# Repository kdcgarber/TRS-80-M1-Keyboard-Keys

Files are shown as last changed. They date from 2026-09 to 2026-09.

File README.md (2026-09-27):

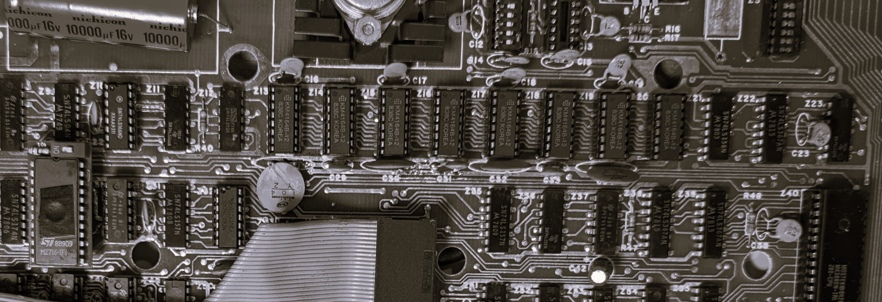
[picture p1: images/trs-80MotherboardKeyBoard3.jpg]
TRS-80-M1-Keyboard-Keys Header


# TRS-80 Model 1 Keyboard Keycaps 
This project is my way of 3D printing my own keycaps for my TRS-80 M1. <br>
I have an M1 motherboard that had no case or keyboard and needed a place to live. <br>
All of the parts needed to do this have been reproduced already by others, but I wanted to play a little more on my own. <br>

This site has .stl and .3mf files I created for my reproduction of my missing 1978 Keycaps.  <br>
For one iteration, I used a modern keyboard with cherry-style keycaps but arranged them with a look to resemble the layout of an original, yet I used an off-the-shelf keyboard.  <br>
Since I was already creating those keys, I thought I'd also create the keys that fit the standard 1978 keys just for fun.  <br>
Even though I didn’t need them currently, it was fun to create and make available for others now to either print their own or take inspiration in their own way to reproduce other keycaps.  <br>

A common element across all the keycaps is the set of glyphs I created to mimic the original Model I keyboard font style.  <br>
I've included those also as .ttf files. In the end, I primarily used Medium .ttf.   <br>
I first tried Regular, but the characters looked too thin.  <br>
I tested Bold as well, but it appeared oversized. So, in true Goldilocks fashion, Medium was just right.  <br>
Because of that, I never went back to refine the Bold version’s glyph shapes. <br>

These keys are inexpensive to reproduce if you have access to a 3D printer.  <br>
The estimated cost of printing a full set in a single-color PLA on my own machine is about $3.37, making them very affordable. <br>

The keys are not really cherry style though they fit the classic + shaped key switches. <br>
I labeled them as cherry because I started with a 60% keyboard that I was replacing that had cherry keycaps.  <br>
The new look is a mix, but maybe more in the DSA keycap style. <br>

There are two styles for the keys with several variations, the Hi-Tek and the Alps. <br>
The Alps I went with a rectangular pattern instead of round stems. <br>
The round stems were a little weaker in design, so I went with the rectangular “+" shape that seemed to work the best. <br>
I don’t have a TRS-80 Alps keyboard to test those on, only the newer "+" shaped keyboards. <br>

<table>
  <tr>
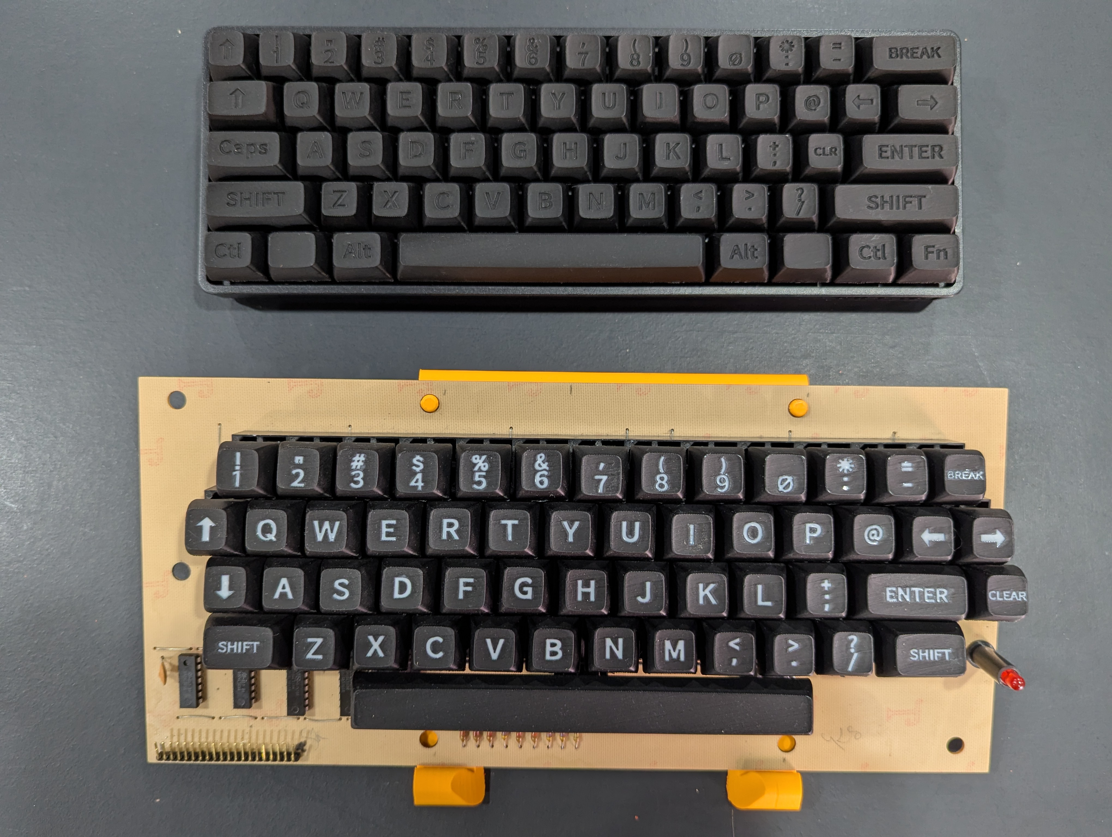
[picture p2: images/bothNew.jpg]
	<td></td>
  </tr>
</table>  

<br>
The keyboard on the top is my Amazon ordered $15 USB keyboard with the new 3d printed keys, next to my first M1 with my replacement 3d PLA keycaps filled then with white UV resin.
Both came out very well, though not profesional purchased keys.
 
## Content in repository
	📂 M1-Fonts		    -- M1 keyboard fonts to be used with key cap creation
	│
	├── TRS80M1-Bold.sfd        - Bold     fontforge editable file
	├── TRS80M1-Bold.ttf        - Bold     Font file
	├── TRS80M1-Medium.sfd      - Medium   fontforge editable file
	├── TRS80M1-Medium.ttf      - Medium   Font file
	├── TRS80M1-Regular.sfd     - Regular  fontforge editable file
	├── TRS80M1-Regular.ttf     - Regular  font file
	│
 	📂 openscad/KeyV2-All
	│
	├─📂 TRS-80-1978-M1/				        -- 1978 style M1 Keys with (HI-Tek) square stems
	│    ├── trs-80-1978-KeyCaps-FromSTL.3mf	-- My edited version I use to print. it's all ready to print more keys
	│    ├── trs-80-1978-KeyCaps.stl		    -- An outputted .stl file with fonts just inset in one color
	│    ├── trs-80-1978-KeyCaps.3mf		    -- An outputted .3mf file with 2 colors if you want to print in 2 colors
	│    └── trs-80-1978-KeyCaps.scad		    -- Run this OpenSCAD file to edit or generate the current keys
	│
	├─📂 TRS-80-1978-M1-KEYPAD/			            -- M1 Key Pad Keys with (Hi-Tek) square stems
	│    ├── trs-80-1978-KeyCaps-KeyPad-FromSTL.3mf	-- My edited version I use to print. it's all ready to print more keys
	│    ├── trs-80-1978-KeyCaps-KeyPad.stl		    -- An outputted .stl file with fonts just inset in one color
	│    ├── trs-80-1978-KeyCaps-KeyPad.3mf		    -- An outputted .3mf file with 2 colors if you want to print in 2 colors
	│    └── trs-80-1978-KeyCaps-KeyPad.scad	    -- Run this OpenSCAD file to edit or generate the current keys
	│
	├─📂 TRS-80-1978-M1-StandardLayoutCherryKeys    				-- Similar the new (ALPS) Cherry key style switches, but only the keys for a new replacment M1 keyboard with the standard + stem connector 
	│    ├── TRS-80-1978-M1-StandardLayoutCherryKeys-FromSTL.3mf	-- My edited version I use to print. it's all ready to print more keys
	│    ├── TRS-80-1978-M1-StandardLayoutCherryKeys.stl			-- An outputted .stl file with fonts just inset in one color
	│    ├── TRS-80-1978-M1-StandardLayoutCherryKeys.3mf			-- An outputted .3mf file with 2 colors if you want to print in 2 colors
	│    └── TRS-80-1978-M1-StandardLayoutCherryKeys.scad			-- Run this OpenSCAD file to edit or generate the current keys
	│
	├─📂 TRS-80-1978-M1-StandardLayoutCherryKeysFlat/			        -- M1 low profile (ALPS) keys with the standard + stem connector 
	│    ├── TRS-80-1978-M1-StandardLayoutCherryKeysFlat-FromSTL.3mf	-- My edited version I use to print. it's all ready to print more keys
	│    ├── TRS-80-1978-M1-StandardLayoutCherryKeysFlat.stl		    -- An outputted .stl file with fonts just inset in one color
	│    ├── TRS-80-1978-M1-StandardLayoutCherryKeysFlat.3mf		    -- An outputted .3mf file with 2 colors if you want to print in 2 colors
	│    └── TRS-80-1978-M1-StandardLayoutCherryKeysFlat.scad	    	-- Run this OpenSCAD file to edit or generate the current keys
	│
	├─📂 TRS-80-1978-M1-StandardLayoutCherryKeysRotatedStems    				-- Similar to the new (ALPS) Cherry key style switches but the stems are rotated for the standard + stem connector 
	│    ├── TRS-80-1978-M1-StandardLayoutCherryKeysRotatedStems-FromSTL.3mf	-- My edited version I use to print. it's all ready to print more keys
	│    ├── TRS-80-1978-M1-StandardLayoutCherryKeysRotatedStems.stl			-- An outputted .stl file with fonts just inset in one color
	│    ├── TRS-80-1978-M1-StandardLayoutCherryKeysRotatedStems.3mf			-- An outputted .3mf file with 2 colors if you want to print in 2 colors
	│    └── TRS-80-1978-M1-StandardLayoutCherryKeysRotatedStems.scad			-- Run this OpenSCAD file to edit or generate the current keys
	│    
	└─📂 TRS-80-M1-60%-Cherry					                -- M1 Keys for a new (ALPS) Cherry key style key switches with the standard + stem connector 
	     ├── trs-80-60% Cherry Key Caps-From-STL.3mf			-- My edited version I use to print. it's all ready to print more keys
	     ├── trs-80-60% Cherry Key Caps.stl				        -- An outputted .stl file with fonts just inset in one color
	     ├── trs-80-60% Cherry Key Caps.3mf				        -- An outputted .3mf file with 2 colors if you want to print in 2 colors
		 └── trs-80-60% Cherry Key Caps.scad			        -- Run this OpenSCAD file to edit or generate the current keys

<br>

## The Keycaps:
I chose to use OpenSCAD to recreate the keycaps for my model 1 keyboards. https://openscad.org/ <br>
I also found a keycap library to get me started which was very helpful.  That template was found at https://github.com/rsheldiii/Keyv2. <br>

I have a Bambu Lab X1 carbon which has a bed size of 256x256x256mm that prints them all very well. <br>
I tried many renditions of the keycaps having the fonts raised and inset and many iterations of placement of the stems of the original keycaps. <br>
I used the regular font shape and only had that single TRS80M1-Medium.ttf installed to ensure I ran with the correct font on the keycaps. <br>

I also recreated characters to represent those on the original keycaps. <br>
I used https://fontforge.org/en-US/downloads/ to help lay those out. <br>
Though none of this is perfect, it creates very nice replacement for M1 keycaps that can be easily 3d printed at home. <br>

The .3mf files that were direct exports of the OpenSCAD creations will print a 2-color keycap if you would prefer. <br>
They do print, but I had poor luck printing any of them in two colors without changing to the Bold font. <br>
I didn’t prefer the look though of the Bold font and chose the two-step approach of adding resin after the single-color print with the medium characters. <br>
My printer does the material handler, so it changes colors for me automatically, though it's purges around 100 times before completing and takes quite a while to print. <br>

In the end I chose the .3mf files with the -FromSTL.3mf ending. <br>
These keycaps are print in a single color with the characters inset in the keycap tops. <br>
I then use a white UV 3d resin to fill the relief and replicate the black keys with white letters. <br>
The resin was added using a craft syringe filled with UV resin and slowly added to each key (also a fiddly task). <br>  
I then set the key under the UV light right away to keep the resin from bleeding into the layer lines. <br>
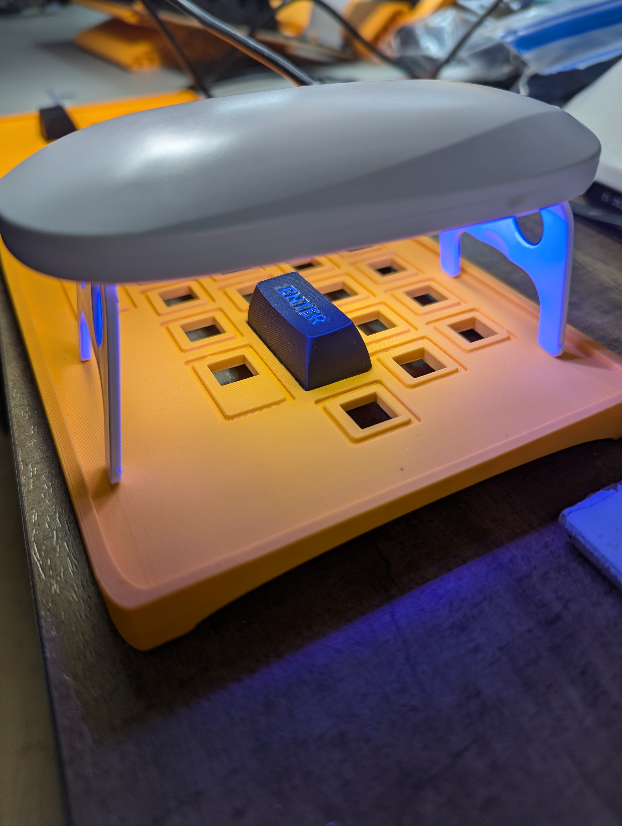
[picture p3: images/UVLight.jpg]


# Samples:

<table>
  <tr>
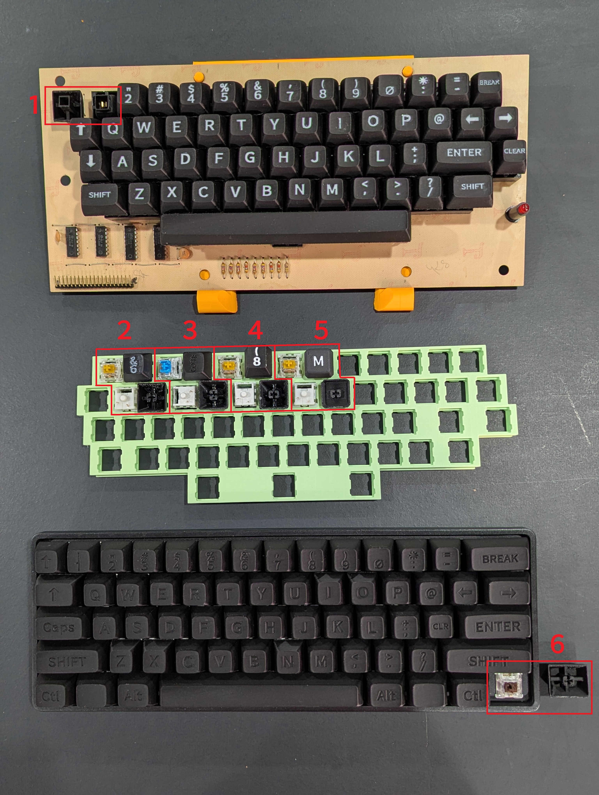
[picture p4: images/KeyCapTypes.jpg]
	<td></td>
  </tr>
</table>

<pre>
1 Original 1978 M1 with square (Hi-Tek) keycap stems
2 Cherry key horizontal and keycap with relief glyphs filled with white resin
3 Keycaps with vertical  layout (this keycap has not been filled with white resin yet)
4 Horizontal black PLA keycaps from .mf3 printed including white PLA glyphs 
5 Horizontal key with low profile black PLA keycaps with white PLA glyphs
6 Standard USB keyboard replaced with black PLA keycaps designed like the 1978 M1 layout
</pre>

### 1978 M1
 -- Number 1 
<table>
  <tr>
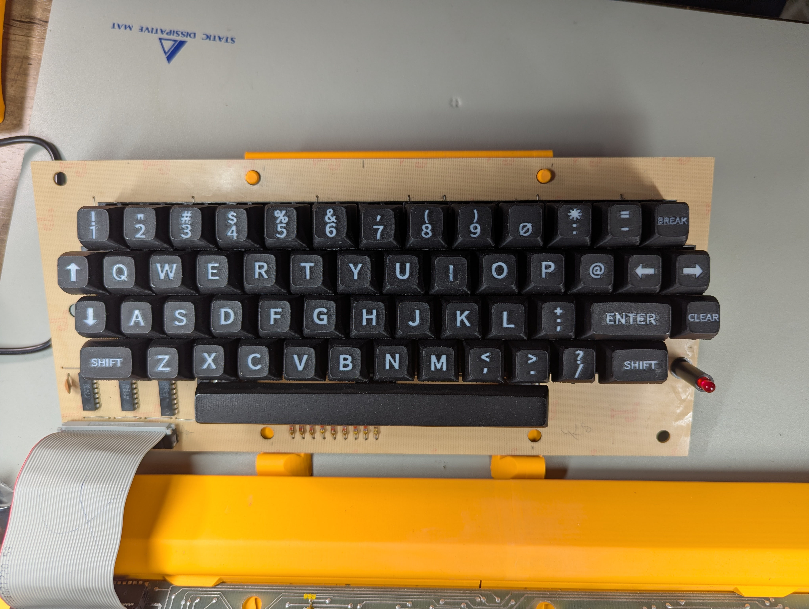
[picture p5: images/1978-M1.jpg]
	<td></td>
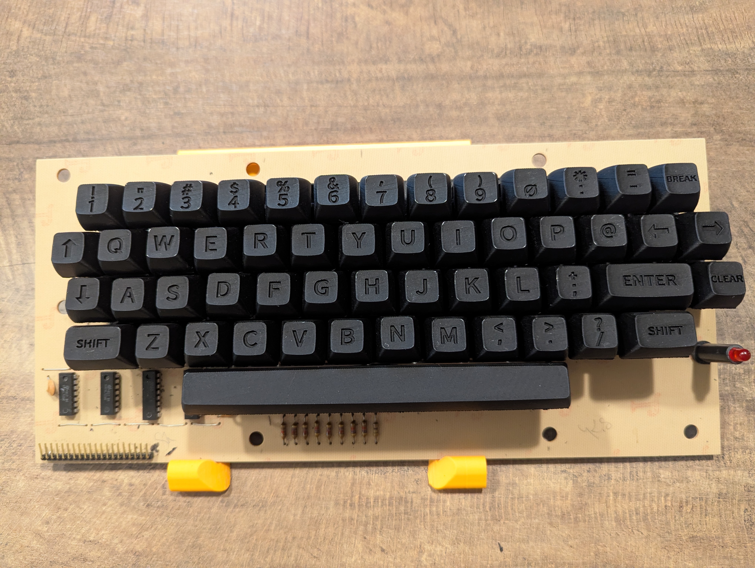
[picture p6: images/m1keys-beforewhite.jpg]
	<td></td>
  </tr>
  <tr>
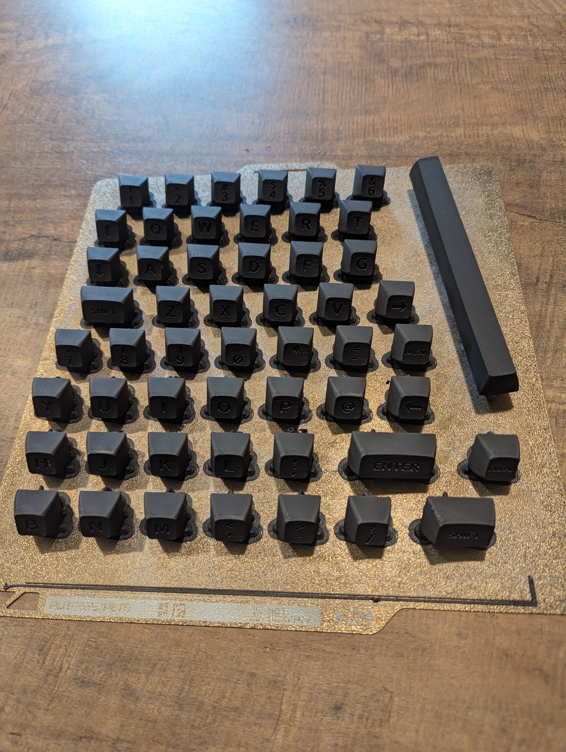
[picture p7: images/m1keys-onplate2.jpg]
	<td></td>
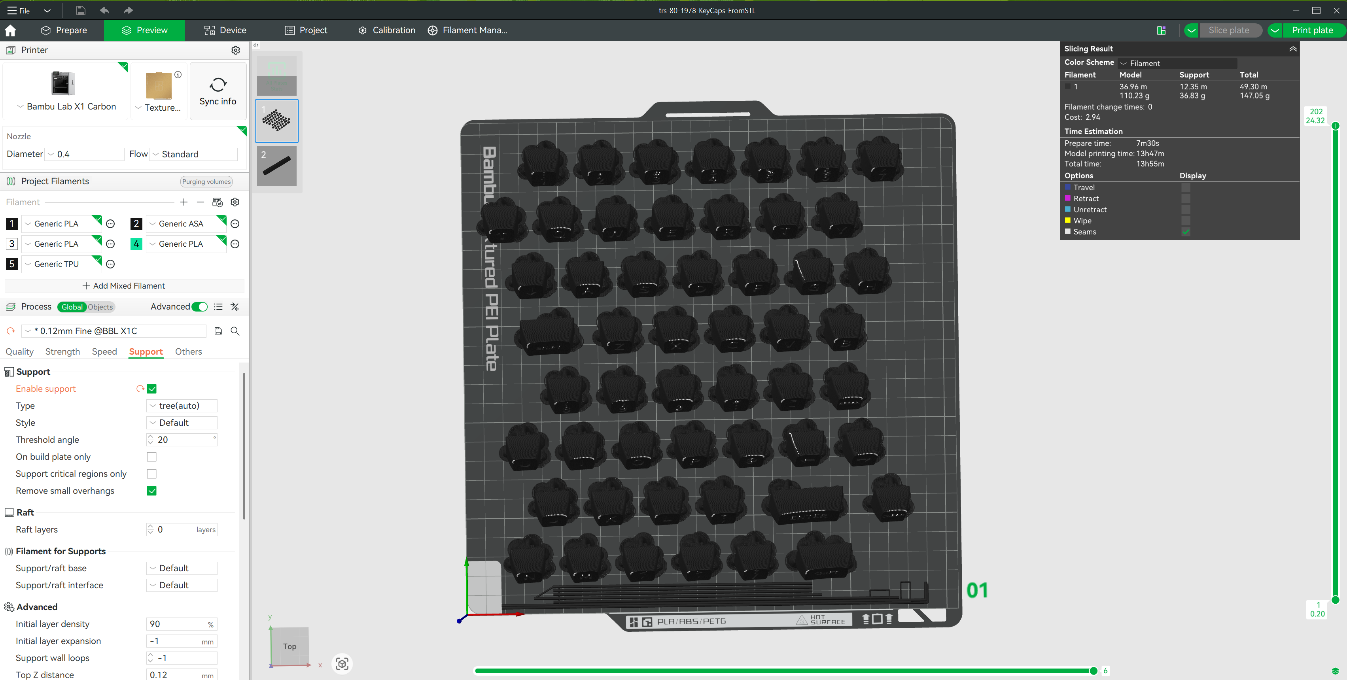
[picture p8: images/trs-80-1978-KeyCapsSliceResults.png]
	<td></td>
  </tr>
    <tr>
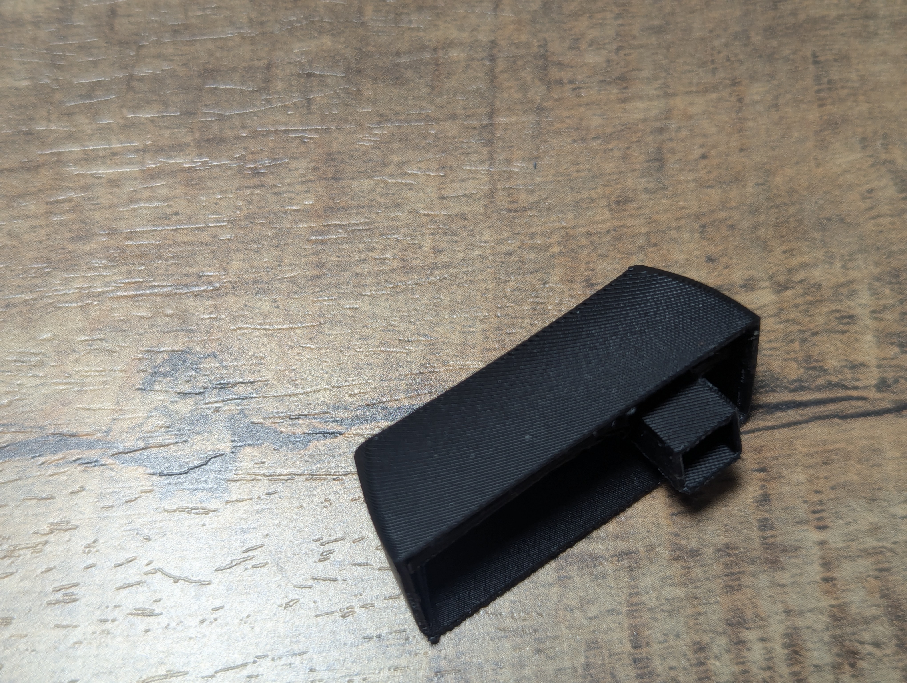
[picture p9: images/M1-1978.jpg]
	<td></td>
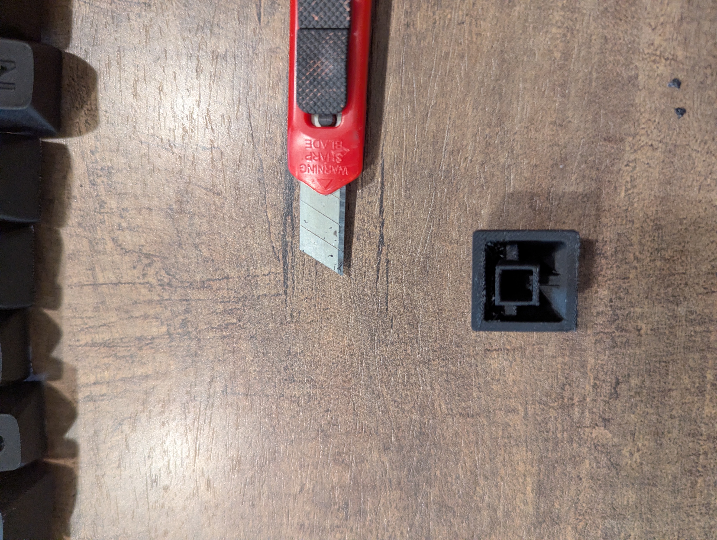
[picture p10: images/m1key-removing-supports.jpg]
	<td></td>
  </tr>
</table>

### 1978 M1 KEYPAD
 -- These go with number 1
<table>
  <tr>
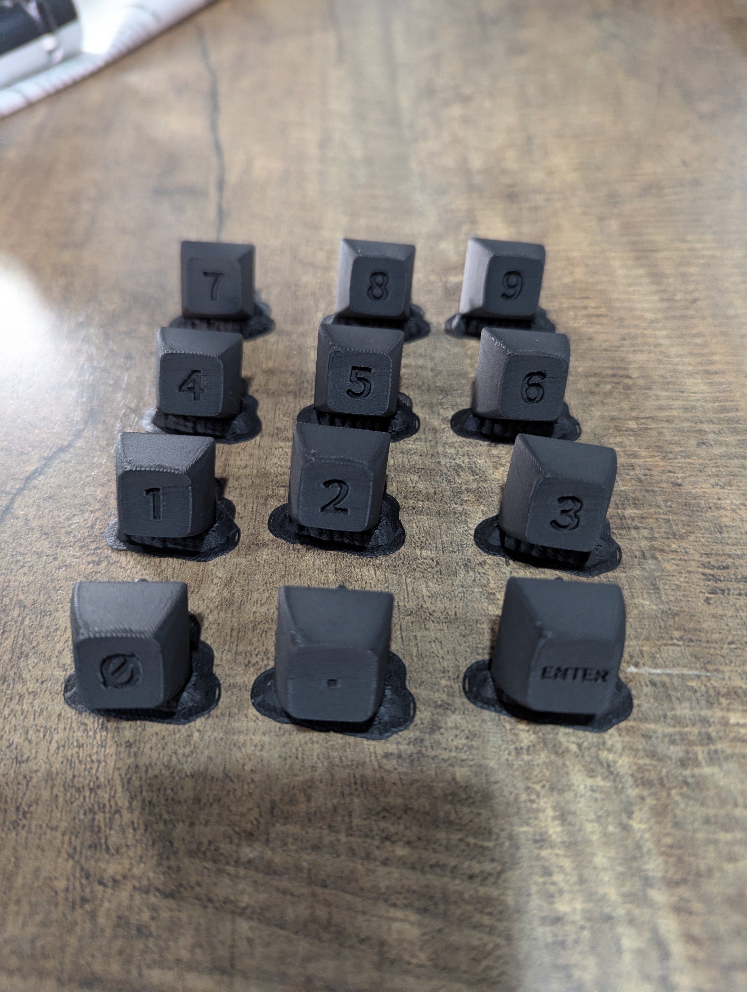
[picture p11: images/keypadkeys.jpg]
	<td></td>
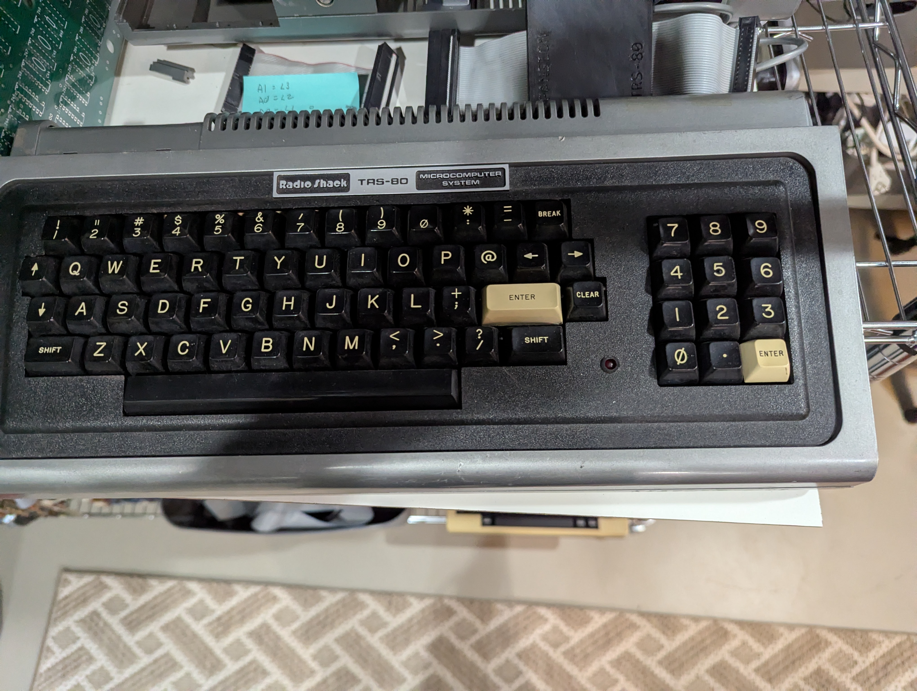
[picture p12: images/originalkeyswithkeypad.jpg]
	<td></td>
  </tr>
</table>

### TRS-80-1978-M1-noLetters
 -- These are just number 6 with no glyphs
### TRS-80-1978-M1-StandardLayoutCherryKeys
 -- Number 2
### TRS-80-1978-M1-StandardLayoutCherryKeysFlat
 -- Number 5
### TRS-80-1978-M1-StandardLayoutCherryKeysRotatedStems
 -- Number 3

### M1 60% Cherry Keys
 -- Number 6
<table>
  <tr>
	<td></td>
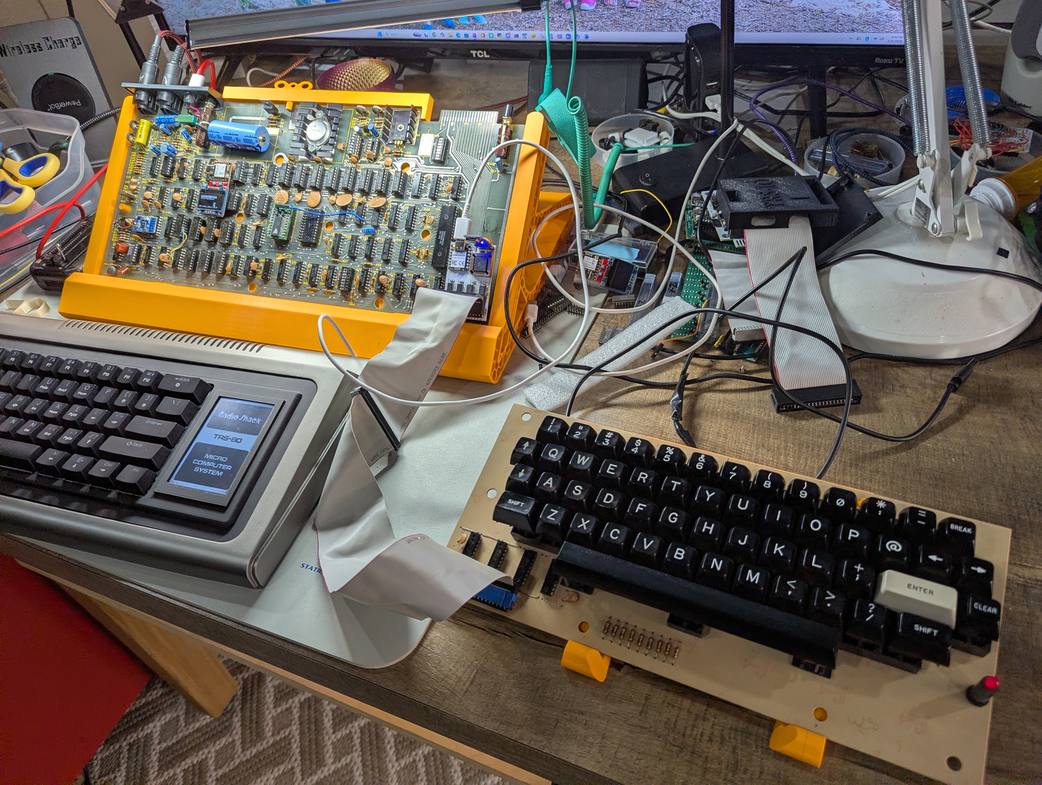
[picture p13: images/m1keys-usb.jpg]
	<td></td>
  </tr>
</table>

## The fonts:
I've installed all 3 ttf files on MS windows 11, but my code for creating keys is using just the Medium definition. <br>
For the caps I only used medium though any of them can be used, so I just installed that single .ttf, Though I've tested and used all 3 types. <br>
I used the windows font manager to look at any/all the installed fonts, and it allows them to be removed also. <br>

To reproduce the keys the included -FromSTL.3mf files or the .stl will print what I've done and none of the other tools need to be installed. <br>

The output of the keys is pre-slanted to reduce the layer lines of rounded corners at them top of keys to make them very smooth with no need to sand and paint. <br>
Because there are supports needed to print the key caps, there will be support removal on each piece which is fiddly. <br>
The final result is a good reproduction that can be reproduced at home and not require a purchased solution. <br>
Though, as mentioned, it’s not perfect. <br>

I used a tool in windows called FontForge to design each glyph in the font file. <br>

### Material used
<pre>
● Glue Syringe Needle Tip Squeeze Bottle                             https://www.amazon.com/dp/B0DD7MFKGP                                                   $6.78
● TINMORRY Matte PLA Filament 1.75 mm, 1 KG, Matte Black             https://www.amazon.com/TINMORRY-Filament-Printing-Compatible-Printers/dp/B0DSFWTXDX   $13.99
● SUNLU Water Washable 3D Printer Resin                              https://www.amazon.com/dp/B0B943KWSQ                                                  $14.56
● HATCHBOX PLA Filament 1.75mm Black, 3D Printer Filament 1KG Spool  https://www.amazon.com/dp/B00J0ECR5I?th=1									           $21.99
</pre>

I tested both types of PLA and even other different color PLA and ASA choices. <br>
I preferer the matte back of the Tinmorry, though matte may not be what everyone likes. <br>

### Next up:
I bought some HATCHBOX black PLA to test. It has a darker slightly glossier finish and looks good. <br>
I'm testing laser etching of keycaps glyphs to see if I can get anything to look good instead of hand filling each keycap. <br>
To start this testing, I created a keycap tray that I printed to hold the keycaps correctly for etching (I hope).
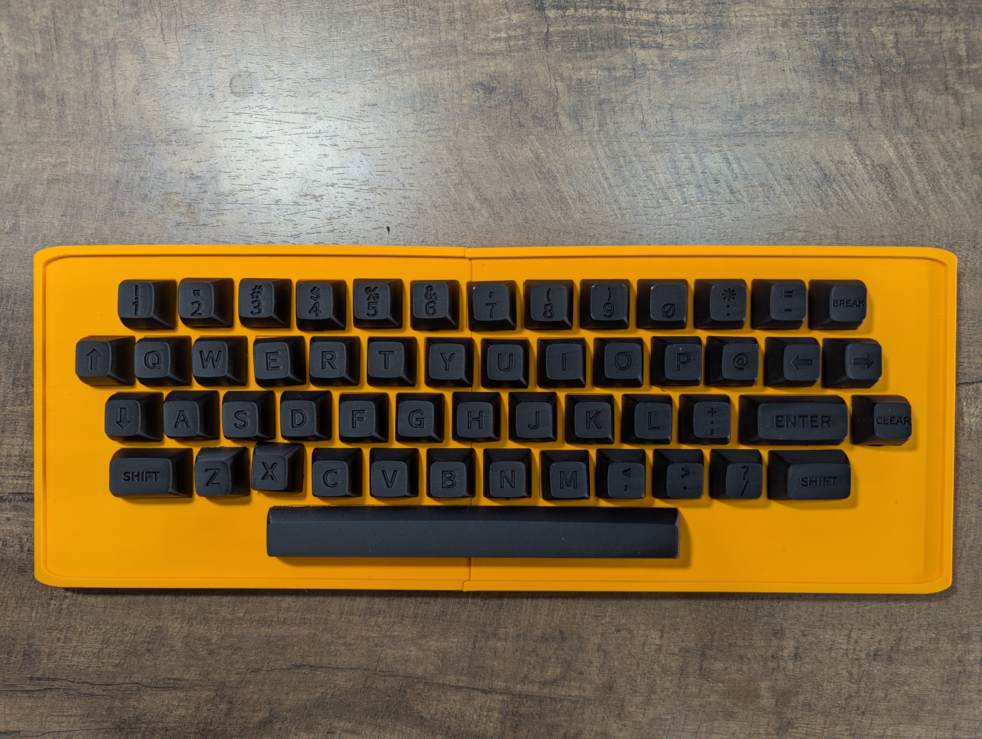
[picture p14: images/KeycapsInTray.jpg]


<br><br>

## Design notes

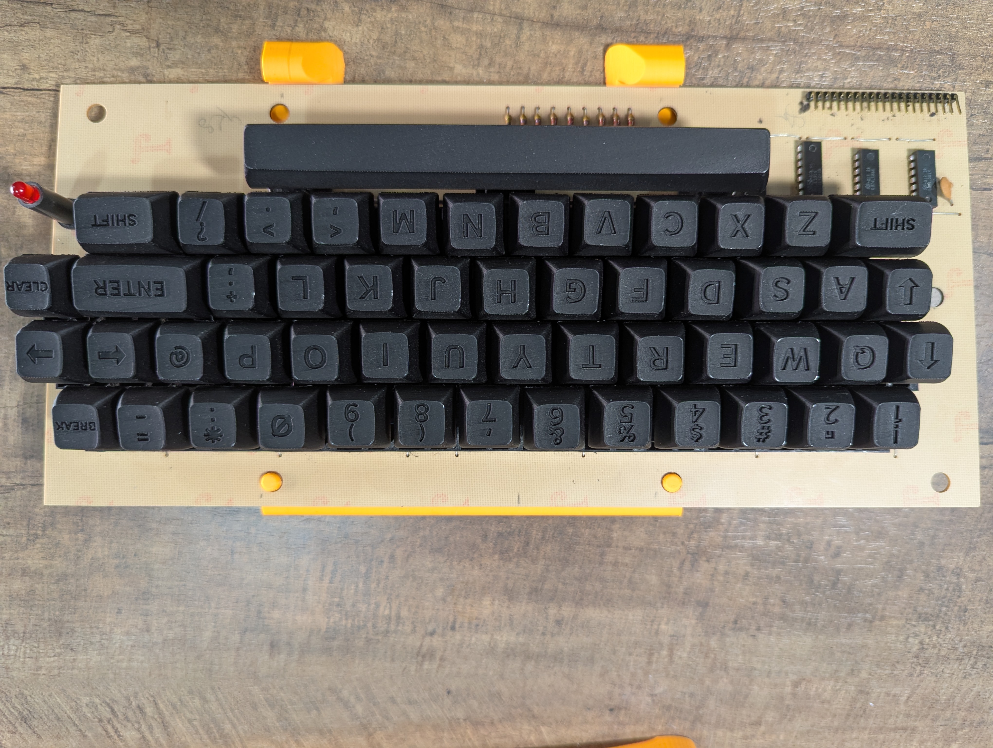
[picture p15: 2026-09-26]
images/UnColored1978-M1.jpg

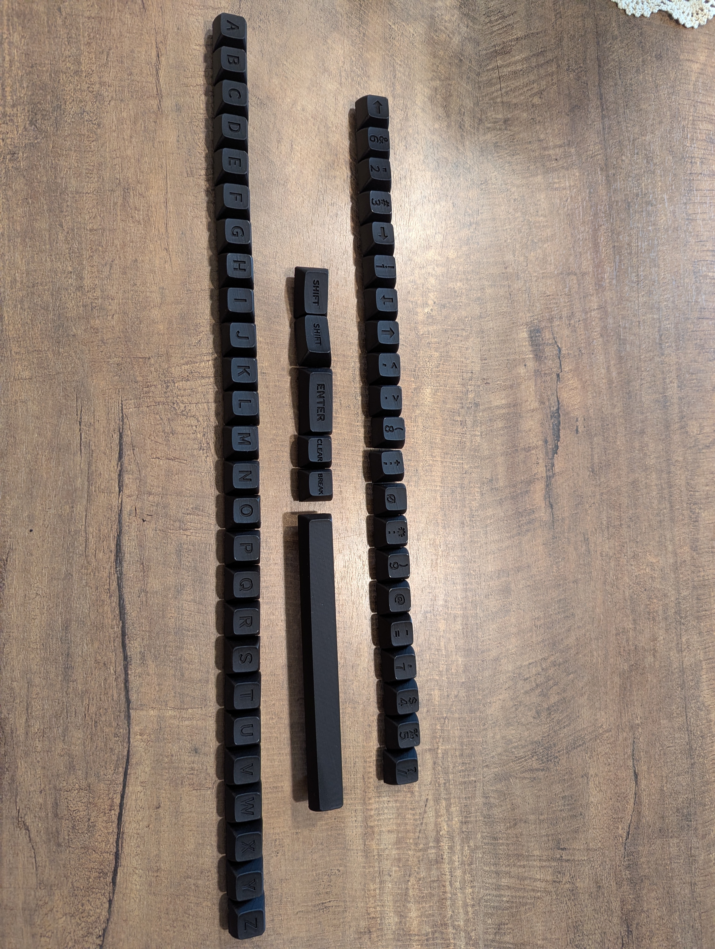
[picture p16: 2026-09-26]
images/m1keys-inline.jpg

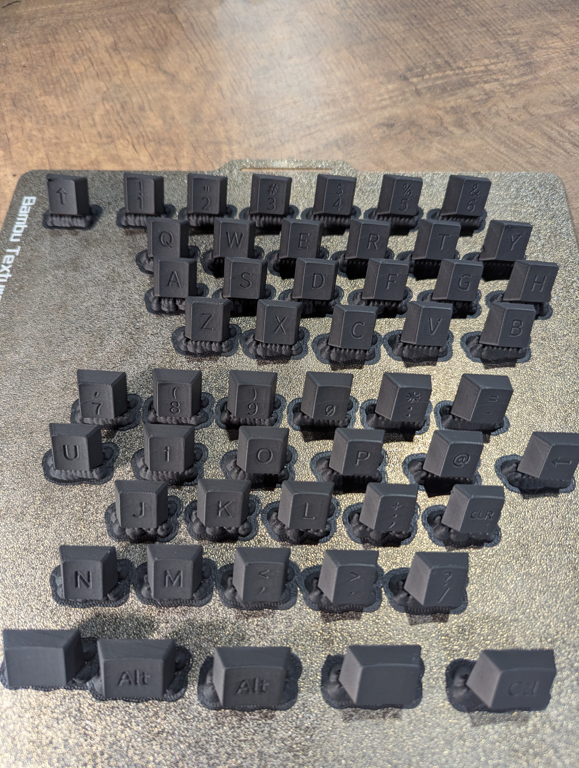
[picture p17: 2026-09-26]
images/m1keys-onplate.jpg

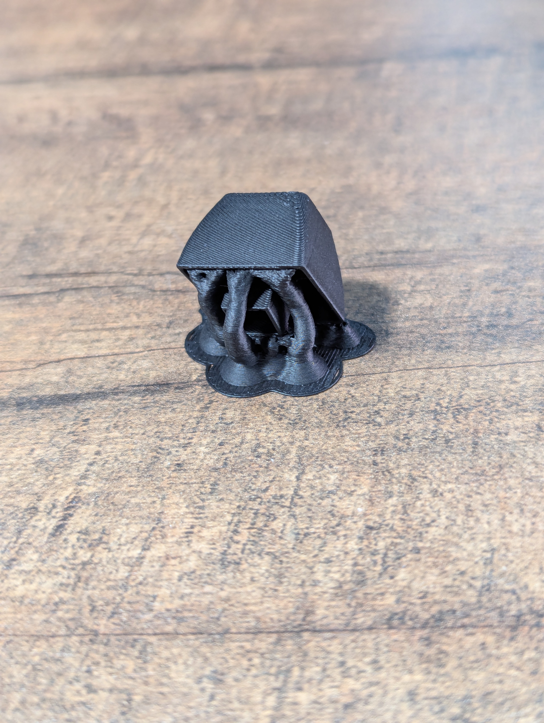
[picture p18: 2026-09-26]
images/SingleKeyCap.jpg

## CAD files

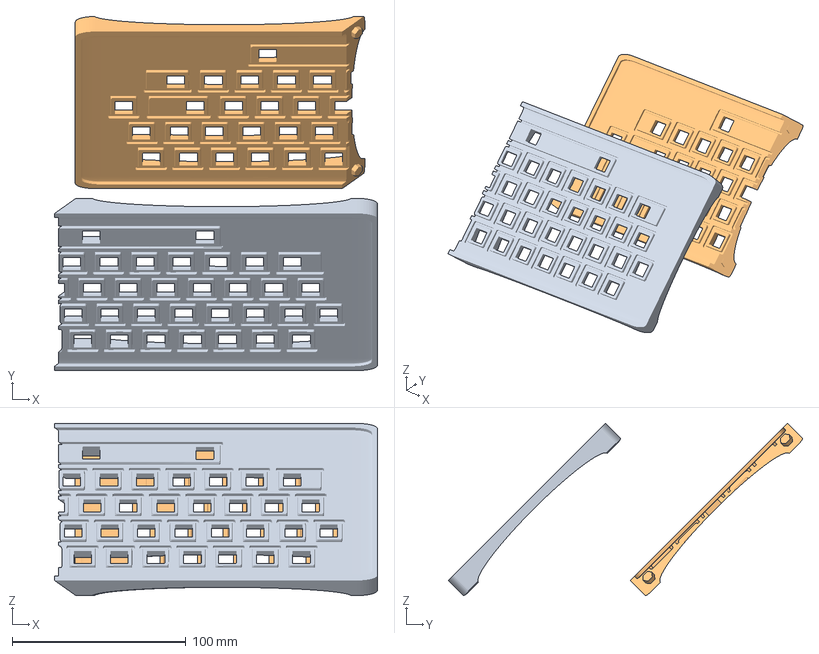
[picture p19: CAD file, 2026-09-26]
KeyCapTray.3mf
186.1 x 204.1 x 99.2 mm
KeyCapTray.stl_A
KeyCapTray.stl_B

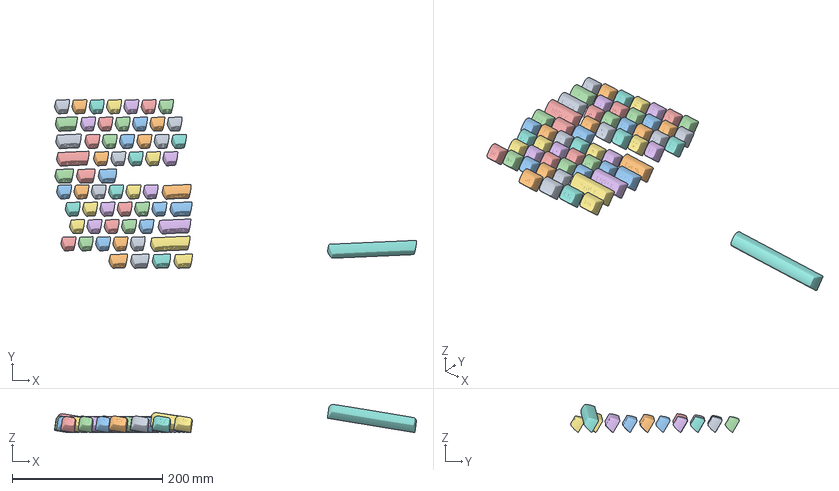
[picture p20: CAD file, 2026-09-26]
openscad/KeyV2-All/TRS-80-1978-M1-KEYPAD/trs-80-1978-KeyCaps-KeyPad-FromSTL.3mf
481.7 x 224.5 x 37.4 mm
trs-80-60% Cherry Key Caps.stl_1
trs-80-60% Cherry Key Caps.stl_2
trs-80-60% Cherry Key Caps.stl_3
trs-80-60% Cherry Key Caps.stl_4
trs-80-60% Cherry Key Caps.stl_5
trs-80-60% Cherry Key Caps.stl_6
trs-80-60% Cherry Key Caps.stl_7
trs-80-60% Cherry Key Caps.stl_8
trs-80-60% Cherry Key Caps.stl_9
trs-80-60% Cherry Key Caps.stl_10
trs-80-60% Cherry Key Caps.stl_11
trs-80-60% Cherry Key Caps.stl_12
trs-80-60% Cherry Key Caps.stl_13
trs-80-60% Cherry Key Caps.stl_14
trs-80-60% Cherry Key Caps.stl_15
trs-80-60% Cherry Key Caps.stl_16
trs-80-60% Cherry Key Caps.stl_17
trs-80-60% Cherry Key Caps.stl_18
trs-80-60% Cherry Key Caps.stl_19
trs-80-60% Cherry Key Caps.stl_20
trs-80-60% Cherry Key Caps.stl_21
trs-80-60% Cherry Key Caps.stl_22
trs-80-60% Cherry Key Caps.stl_23
trs-80-60% Cherry Key Caps.stl_24
trs-80-60% Cherry Key Caps.stl_25
trs-80-60% Cherry Key Caps.stl_26
trs-80-60% Cherry Key Caps.stl_27
trs-80-60% Cherry Key Caps.stl_28
trs-80-60% Cherry Key Caps.stl_29
trs-80-60% Cherry Key Caps.stl_30
trs-80-60% Cherry Key Caps.stl_31
trs-80-60% Cherry Key Caps.stl_32
trs-80-60% Cherry Key Caps.stl_33
trs-80-60% Cherry Key Caps.stl_34
trs-80-60% Cherry Key Caps.stl_35
trs-80-60% Cherry Key Caps.stl_36
trs-80-60% Cherry Key Caps.stl_37
trs-80-60% Cherry Key Caps.stl_38
trs-80-60% Cherry Key Caps.stl_39
trs-80-60% Cherry Key Caps.stl_40
trs-80-60% Cherry Key Caps.stl_41
trs-80-60% Cherry Key Caps.stl_42
trs-80-60% Cherry Key Caps.stl_43
trs-80-60% Cherry Key Caps.stl_44
trs-80-60% Cherry Key Caps.stl_45
trs-80-60% Cherry Key Caps.stl_46
trs-80-60% Cherry Key Caps.stl_47
trs-80-60% Cherry Key Caps.stl_48
trs-80-60% Cherry Key Caps.stl_49
trs-80-60% Cherry Key Caps.stl_50
trs-80-60% Cherry Key Caps.stl_51
trs-80-60% Cherry Key Caps.stl_52
trs-80-60% Cherry Key Caps.stl_53
trs-80-60% Cherry Key Caps.stl_54
trs-80-60% Cherry Key Caps.stl_55
trs-80-60% Cherry Key Caps.stl_56
trs-80-60% Cherry Key Caps.stl_57
trs-80-60% Cherry Key Caps.stl_58
trs-80-60% Cherry Key Caps.stl_59
trs-80-60% Cherry Key Caps.stl_60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

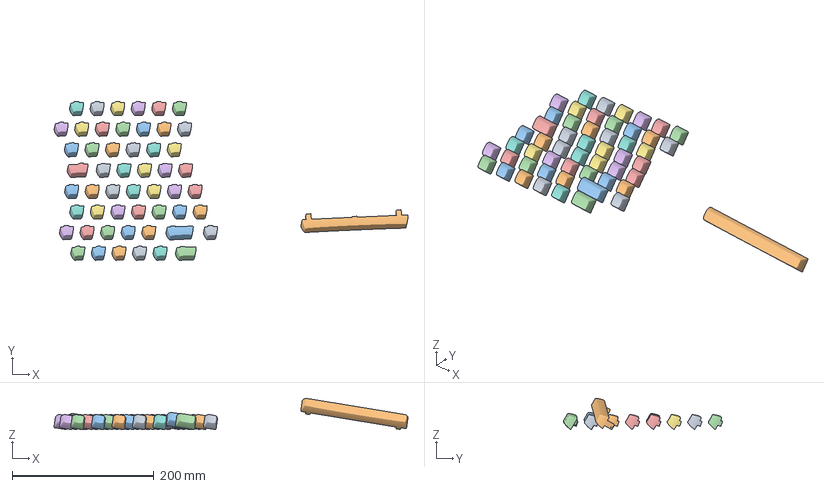
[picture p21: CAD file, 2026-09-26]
openscad/KeyV2-All/TRS-80-1978-M1-noLetters/trs-80-1978-KeyCaps-FromSTL.3mf
499.9 x 224.4 x 44.1 mm
trs-80-1978-KeyCaps.stl_1
trs-80-1978-KeyCaps.stl_2
trs-80-1978-KeyCaps.stl_3
trs-80-1978-KeyCaps.stl_4
trs-80-1978-KeyCaps.stl_5
trs-80-1978-KeyCaps.stl_6
trs-80-1978-KeyCaps.stl_7
trs-80-1978-KeyCaps.stl_8
trs-80-1978-KeyCaps.stl_9
trs-80-1978-KeyCaps.stl_10
trs-80-1978-KeyCaps.stl_11
trs-80-1978-KeyCaps.stl_12
trs-80-1978-KeyCaps.stl_13
trs-80-1978-KeyCaps.stl_14
trs-80-1978-KeyCaps.stl_15
trs-80-1978-KeyCaps.stl_16
trs-80-1978-KeyCaps.stl_17
trs-80-1978-KeyCaps.stl_18
trs-80-1978-KeyCaps.stl_19
trs-80-1978-KeyCaps.stl_20
trs-80-1978-KeyCaps.stl_21
trs-80-1978-KeyCaps.stl_22
trs-80-1978-KeyCaps.stl_23
trs-80-1978-KeyCaps.stl_24
trs-80-1978-KeyCaps.stl_25
trs-80-1978-KeyCaps.stl_26
trs-80-1978-KeyCaps.stl_27
trs-80-1978-KeyCaps.stl_28
trs-80-1978-KeyCaps.stl_29
trs-80-1978-KeyCaps.stl_30
trs-80-1978-KeyCaps.stl_31
trs-80-1978-KeyCaps.stl_32
trs-80-1978-KeyCaps.stl_33
trs-80-1978-KeyCaps.stl_34
trs-80-1978-KeyCaps.stl_35
trs-80-1978-KeyCaps.stl_36
trs-80-1978-KeyCaps.stl_37
trs-80-1978-KeyCaps.stl_38
trs-80-1978-KeyCaps.stl_39
trs-80-1978-KeyCaps.stl_40
trs-80-1978-KeyCaps.stl_41
trs-80-1978-KeyCaps.stl_42
trs-80-1978-KeyCaps.stl_43
trs-80-1978-KeyCaps.stl_44
trs-80-1978-KeyCaps.stl_45
trs-80-1978-KeyCaps.stl_46
trs-80-1978-KeyCaps.stl_47
trs-80-1978-KeyCaps.stl_48
trs-80-1978-KeyCaps.stl_49
trs-80-1978-KeyCaps.stl_50
trs-80-1978-KeyCaps.stl_51
trs-80-1978-KeyCaps.stl_52
trs-80-1978-KeyCaps.stl_53

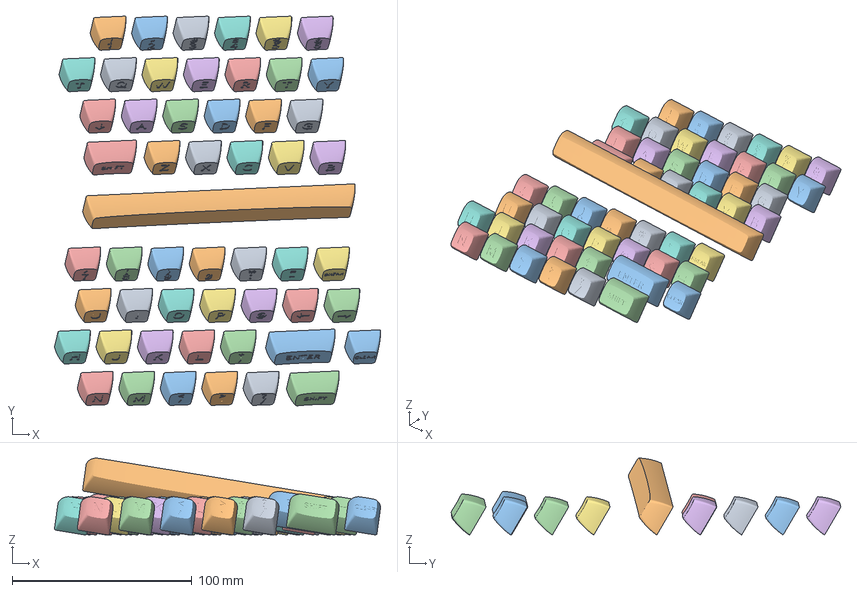
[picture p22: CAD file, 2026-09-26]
openscad/KeyV2-All/TRS-80-1978-M1-StandardLayoutCherryKeys/TRS-80-1978-M1-StandardLayoutCherryKeys-FromSTL3mf.3mf
181.3 x 216.7 x 42.8 mm
TRS-80-1978-M1-StandardLayoutCherryKeys.stl_1
TRS-80-1978-M1-StandardLayoutCherryKeys.stl_2
TRS-80-1978-M1-StandardLayoutCherryKeys.stl_3
TRS-80-1978-M1-StandardLayoutCherryKeys.stl_4
TRS-80-1978-M1-StandardLayoutCherryKeys.stl_5
TRS-80-1978-M1-StandardLayoutCherryKeys.stl_6
TRS-80-1978-M1-StandardLayoutCherryKeys.stl_7
TRS-80-1978-M1-StandardLayoutCherryKeys.stl_8
TRS-80-1978-M1-StandardLayoutCherryKeys.stl_9
TRS-80-1978-M1-StandardLayoutCherryKeys.stl_10
TRS-80-1978-M1-StandardLayoutCherryKeys.stl_11
TRS-80-1978-M1-StandardLayoutCherryKeys.stl_12
TRS-80-1978-M1-StandardLayoutCherryKeys.stl_13
TRS-80-1978-M1-StandardLayoutCherryKeys.stl_14
TRS-80-1978-M1-StandardLayoutCherryKeys.stl_15
TRS-80-1978-M1-StandardLayoutCherryKeys.stl_16
TRS-80-1978-M1-StandardLayoutCherryKeys.stl_17
TRS-80-1978-M1-StandardLayoutCherryKeys.stl_18
TRS-80-1978-M1-StandardLayoutCherryKeys.stl_19
TRS-80-1978-M1-StandardLayoutCherryKeys.stl_20
TRS-80-1978-M1-StandardLayoutCherryKeys.stl_21
TRS-80-1978-M1-StandardLayoutCherryKeys.stl_22
TRS-80-1978-M1-StandardLayoutCherryKeys.stl_23
TRS-80-1978-M1-StandardLayoutCherryKeys.stl_24
TRS-80-1978-M1-StandardLayoutCherryKeys.stl_25
TRS-80-1978-M1-StandardLayoutCherryKeys.stl_26
TRS-80-1978-M1-StandardLayoutCherryKeys.stl_27
TRS-80-1978-M1-StandardLayoutCherryKeys.stl_28
TRS-80-1978-M1-StandardLayoutCherryKeys.stl_29
TRS-80-1978-M1-StandardLayoutCherryKeys.stl_30
TRS-80-1978-M1-StandardLayoutCherryKeys.stl_31
TRS-80-1978-M1-StandardLayoutCherryKeys.stl_32
TRS-80-1978-M1-StandardLayoutCherryKeys.stl_33
TRS-80-1978-M1-StandardLayoutCherryKeys.stl_34
TRS-80-1978-M1-StandardLayoutCherryKeys.stl_35
TRS-80-1978-M1-StandardLayoutCherryKeys.stl_36
TRS-80-1978-M1-StandardLayoutCherryKeys.stl_37
TRS-80-1978-M1-StandardLayoutCherryKeys.stl_38
TRS-80-1978-M1-StandardLayoutCherryKeys.stl_39
TRS-80-1978-M1-StandardLayoutCherryKeys.stl_40
TRS-80-1978-M1-StandardLayoutCherryKeys.stl_41
TRS-80-1978-M1-StandardLayoutCherryKeys.stl_42
TRS-80-1978-M1-StandardLayoutCherryKeys.stl_43
TRS-80-1978-M1-StandardLayoutCherryKeys.stl_44
TRS-80-1978-M1-StandardLayoutCherryKeys.stl_45
TRS-80-1978-M1-StandardLayoutCherryKeys.stl_46
TRS-80-1978-M1-StandardLayoutCherryKeys.stl_47
TRS-80-1978-M1-StandardLayoutCherryKeys.stl_48
TRS-80-1978-M1-StandardLayoutCherryKeys.stl_49
TRS-80-1978-M1-StandardLayoutCherryKeys.stl_50
TRS-80-1978-M1-StandardLayoutCherryKeys.stl_51
TRS-80-1978-M1-StandardLayoutCherryKeys.stl_52
TRS-80-1978-M1-StandardLayoutCherryKeys.stl_53

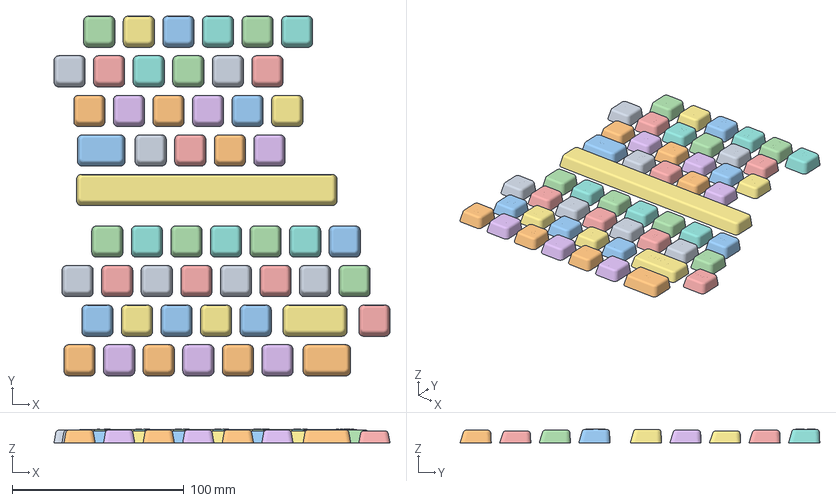
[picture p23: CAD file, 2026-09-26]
openscad/KeyV2-All/TRS-80-1978-M1-StandardLayoutCherryKeysFlat/TRS-80-1978-M1-StandardLayoutCherryKeysFlat.3mf
195.7 x 209.5 x 7.90 mm

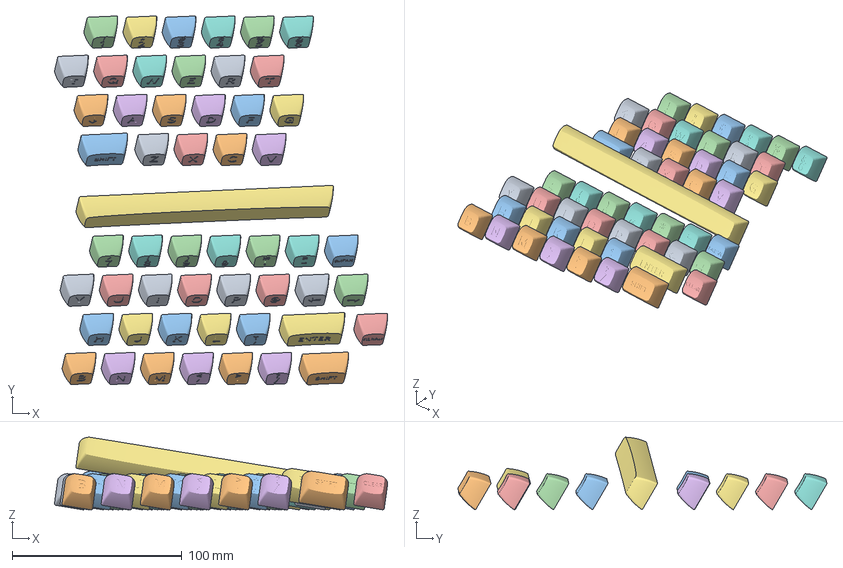
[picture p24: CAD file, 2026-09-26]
openscad/KeyV2-All/TRS-80-1978-M1-StandardLayoutCherryKeysRotatedStems/TRS-80-1978-M1-StandardLayoutCherryKeysRotatedStems.3mf
196.1 x 217.3 x 42.8 mm

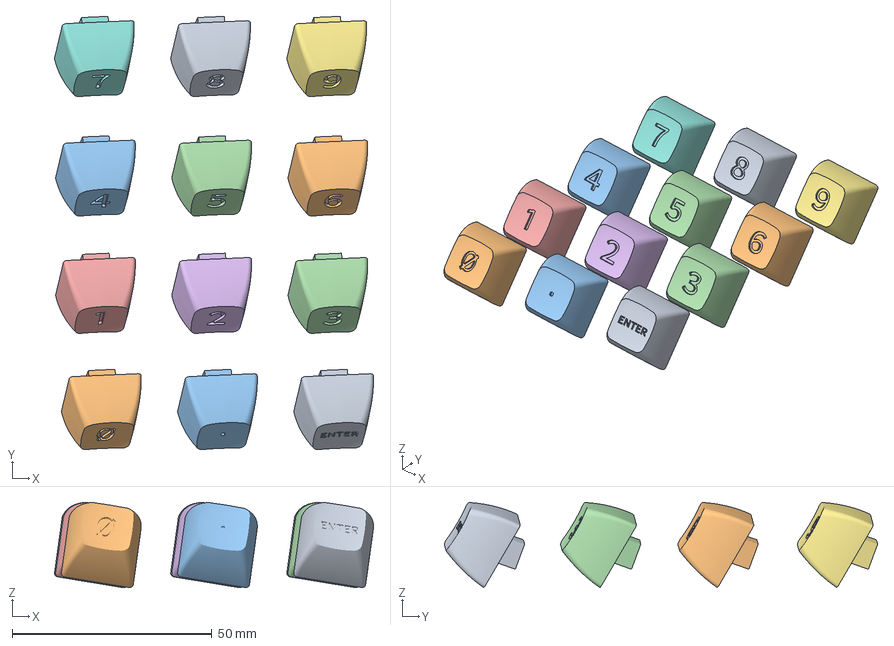
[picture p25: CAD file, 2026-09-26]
openscad/KeyV2-All/TRS-80-1978-M1/trs-80-1978-KeyCaps-KeyPad.3mf
79.8 x 108.3 x 21.3 mm
trs-80-1978-KeyCaps-KeyPad.stl_1
trs-80-1978-KeyCaps-KeyPad.stl_2
trs-80-1978-KeyCaps-KeyPad.stl_3
trs-80-1978-KeyCaps-KeyPad.stl_4
trs-80-1978-KeyCaps-KeyPad.stl_5
trs-80-1978-KeyCaps-KeyPad.stl_6
trs-80-1978-KeyCaps-KeyPad.stl_7
trs-80-1978-KeyCaps-KeyPad.stl_8
trs-80-1978-KeyCaps-KeyPad.stl_9
trs-80-1978-KeyCaps-KeyPad.stl_10
trs-80-1978-KeyCaps-KeyPad.stl_11
trs-80-1978-KeyCaps-KeyPad.stl_12

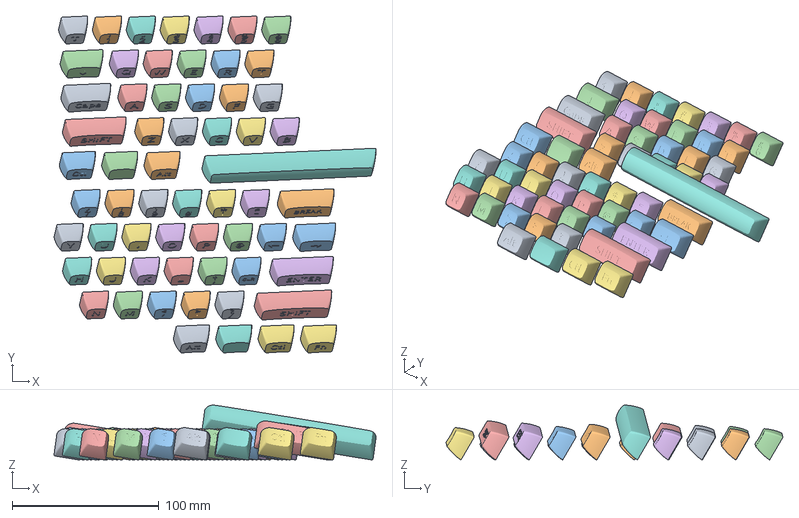
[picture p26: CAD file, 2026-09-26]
openscad/KeyV2-All/TRS-80-M1-60%-Cherry/trs-80-60% Cherry Key Caps-FromSTL.3mf
219.2 x 229.3 x 37.4 mm
trs-80-60% Cherry Key Caps.stl_1
trs-80-60% Cherry Key Caps.stl_2
trs-80-60% Cherry Key Caps.stl_3
trs-80-60% Cherry Key Caps.stl_4
trs-80-60% Cherry Key Caps.stl_5
trs-80-60% Cherry Key Caps.stl_6
trs-80-60% Cherry Key Caps.stl_7
trs-80-60% Cherry Key Caps.stl_8
trs-80-60% Cherry Key Caps.stl_9
trs-80-60% Cherry Key Caps.stl_10
trs-80-60% Cherry Key Caps.stl_11
trs-80-60% Cherry Key Caps.stl_12
trs-80-60% Cherry Key Caps.stl_13
trs-80-60% Cherry Key Caps.stl_14
trs-80-60% Cherry Key Caps.stl_15
trs-80-60% Cherry Key Caps.stl_16
trs-80-60% Cherry Key Caps.stl_17
trs-80-60% Cherry Key Caps.stl_18
trs-80-60% Cherry Key Caps.stl_19
trs-80-60% Cherry Key Caps.stl_20
trs-80-60% Cherry Key Caps.stl_21
trs-80-60% Cherry Key Caps.stl_22
trs-80-60% Cherry Key Caps.stl_23
trs-80-60% Cherry Key Caps.stl_24
trs-80-60% Cherry Key Caps.stl_25
trs-80-60% Cherry Key Caps.stl_26
trs-80-60% Cherry Key Caps.stl_27
trs-80-60% Cherry Key Caps.stl_28
trs-80-60% Cherry Key Caps.stl_29
trs-80-60% Cherry Key Caps.stl_30
trs-80-60% Cherry Key Caps.stl_31
trs-80-60% Cherry Key Caps.stl_32
trs-80-60% Cherry Key Caps.stl_33
trs-80-60% Cherry Key Caps.stl_34
trs-80-60% Cherry Key Caps.stl_35
trs-80-60% Cherry Key Caps.stl_36
trs-80-60% Cherry Key Caps.stl_37
trs-80-60% Cherry Key Caps.stl_38
trs-80-60% Cherry Key Caps.stl_39
trs-80-60% Cherry Key Caps.stl_40
trs-80-60% Cherry Key Caps.stl_41
trs-80-60% Cherry Key Caps.stl_42
trs-80-60% Cherry Key Caps.stl_43
trs-80-60% Cherry Key Caps.stl_44
trs-80-60% Cherry Key Caps.stl_45
trs-80-60% Cherry Key Caps.stl_46
trs-80-60% Cherry Key Caps.stl_47
trs-80-60% Cherry Key Caps.stl_48
trs-80-60% Cherry Key Caps.stl_49
trs-80-60% Cherry Key Caps.stl_50
trs-80-60% Cherry Key Caps.stl_51
trs-80-60% Cherry Key Caps.stl_52
trs-80-60% Cherry Key Caps.stl_53
trs-80-60% Cherry Key Caps.stl_54
trs-80-60% Cherry Key Caps.stl_55
trs-80-60% Cherry Key Caps.stl_56
trs-80-60% Cherry Key Caps.stl_57
trs-80-60% Cherry Key Caps.stl_58
trs-80-60% Cherry Key Caps.stl_59
trs-80-60% Cherry Key Caps.stl_60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

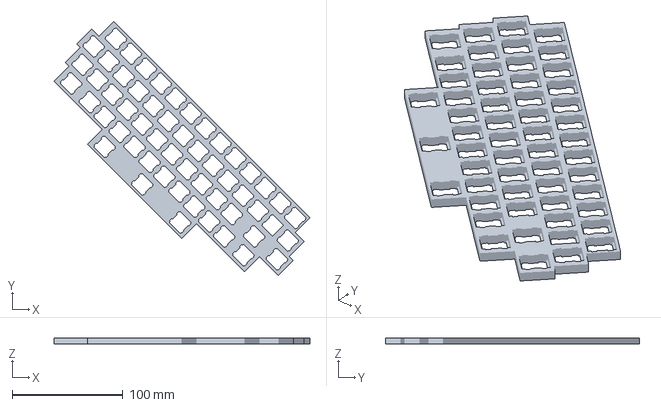
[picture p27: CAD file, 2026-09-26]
KeyCapGrid.3mf
231.0 x 229.1 x 5.00 mm

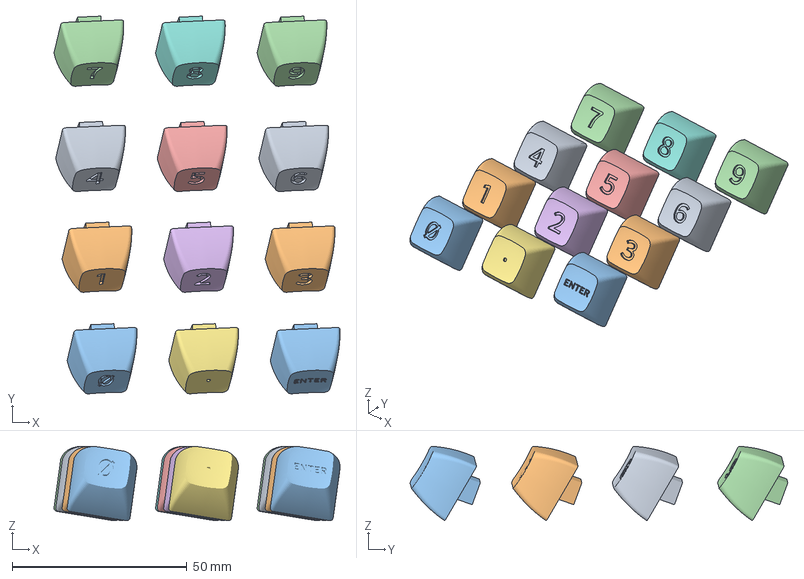
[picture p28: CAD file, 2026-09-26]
openscad/KeyV2-All/TRS-80-1978-M1-KEYPAD/trs-80-1978-KeyCaps-KeyPad.3mf
81.8 x 108.0 x 21.3 mm

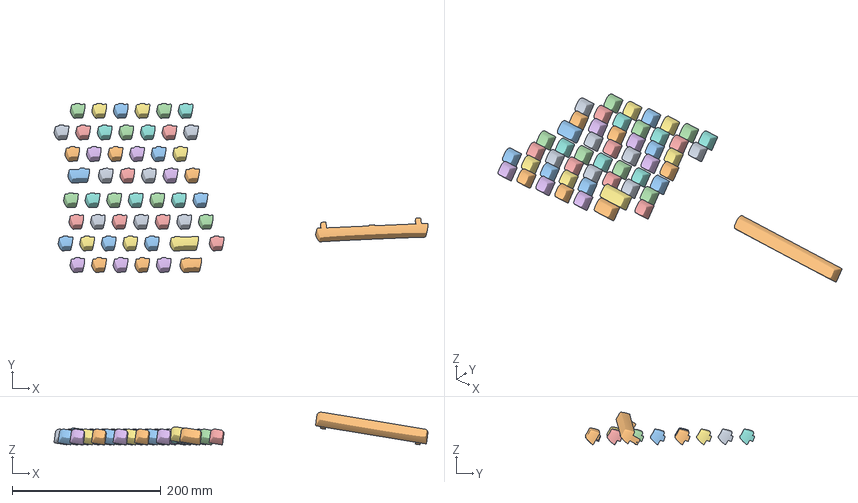
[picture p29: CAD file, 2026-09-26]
openscad/KeyV2-All/TRS-80-1978-M1-noLetters/trs-80-1978-KeyCaps.3mf
503.3 x 227.7 x 44.1 mm

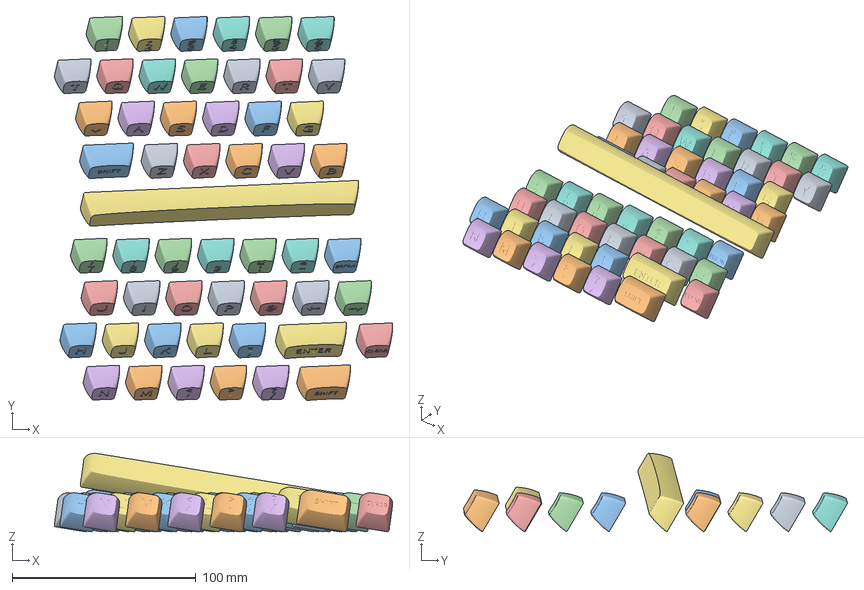
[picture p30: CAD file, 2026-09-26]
openscad/KeyV2-All/TRS-80-1978-M1-StandardLayoutCherryKeys/TRS-80-1978-M1-StandardLayoutCherryKeys.3mf
184.3 x 209.1 x 42.8 mm

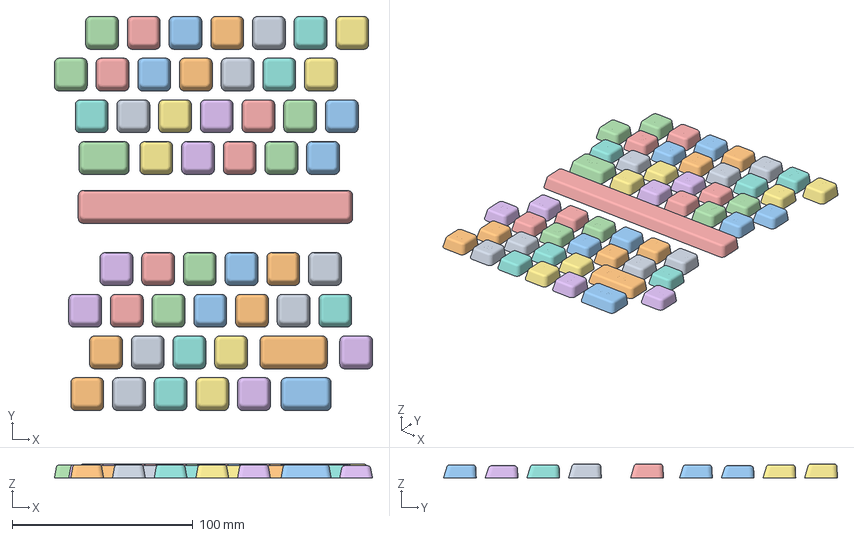
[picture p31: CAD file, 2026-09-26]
openscad/KeyV2-All/TRS-80-1978-M1-StandardLayoutCherryKeysFlat/TRS-80-1978-M1-StandardLayoutCherryKeysFlat-FromSTL.3mf
175.9 x 217.8 x 7.90 mm
TRS-80-1978-M1-StandardLayoutCherryKeysFlat.stl_1
TRS-80-1978-M1-StandardLayoutCherryKeysFlat.stl_2
TRS-80-1978-M1-StandardLayoutCherryKeysFlat.stl_3
TRS-80-1978-M1-StandardLayoutCherryKeysFlat.stl_4
TRS-80-1978-M1-StandardLayoutCherryKeysFlat.stl_5
TRS-80-1978-M1-StandardLayoutCherryKeysFlat.stl_6
TRS-80-1978-M1-StandardLayoutCherryKeysFlat.stl_7
TRS-80-1978-M1-StandardLayoutCherryKeysFlat.stl_8
TRS-80-1978-M1-StandardLayoutCherryKeysFlat.stl_9
TRS-80-1978-M1-StandardLayoutCherryKeysFlat.stl_10
TRS-80-1978-M1-StandardLayoutCherryKeysFlat.stl_11
TRS-80-1978-M1-StandardLayoutCherryKeysFlat.stl_12
TRS-80-1978-M1-StandardLayoutCherryKeysFlat.stl_13
TRS-80-1978-M1-StandardLayoutCherryKeysFlat.stl_14
TRS-80-1978-M1-StandardLayoutCherryKeysFlat.stl_15
TRS-80-1978-M1-StandardLayoutCherryKeysFlat.stl_16
TRS-80-1978-M1-StandardLayoutCherryKeysFlat.stl_17
TRS-80-1978-M1-StandardLayoutCherryKeysFlat.stl_18
TRS-80-1978-M1-StandardLayoutCherryKeysFlat.stl_19
TRS-80-1978-M1-StandardLayoutCherryKeysFlat.stl_20
TRS-80-1978-M1-StandardLayoutCherryKeysFlat.stl_21
TRS-80-1978-M1-StandardLayoutCherryKeysFlat.stl_22
TRS-80-1978-M1-StandardLayoutCherryKeysFlat.stl_23
TRS-80-1978-M1-StandardLayoutCherryKeysFlat.stl_24
TRS-80-1978-M1-StandardLayoutCherryKeysFlat.stl_25
TRS-80-1978-M1-StandardLayoutCherryKeysFlat.stl_26
TRS-80-1978-M1-StandardLayoutCherryKeysFlat.stl_27
TRS-80-1978-M1-StandardLayoutCherryKeysFlat.stl_28
TRS-80-1978-M1-StandardLayoutCherryKeysFlat.stl_29
TRS-80-1978-M1-StandardLayoutCherryKeysFlat.stl_30
TRS-80-1978-M1-StandardLayoutCherryKeysFlat.stl_31
TRS-80-1978-M1-StandardLayoutCherryKeysFlat.stl_32
TRS-80-1978-M1-StandardLayoutCherryKeysFlat.stl_33
TRS-80-1978-M1-StandardLayoutCherryKeysFlat.stl_34
TRS-80-1978-M1-StandardLayoutCherryKeysFlat.stl_35
TRS-80-1978-M1-StandardLayoutCherryKeysFlat.stl_36
TRS-80-1978-M1-StandardLayoutCherryKeysFlat.stl_37
TRS-80-1978-M1-StandardLayoutCherryKeysFlat.stl_38
TRS-80-1978-M1-StandardLayoutCherryKeysFlat.stl_39
TRS-80-1978-M1-StandardLayoutCherryKeysFlat.stl_40
TRS-80-1978-M1-StandardLayoutCherryKeysFlat.stl_41
TRS-80-1978-M1-StandardLayoutCherryKeysFlat.stl_42
TRS-80-1978-M1-StandardLayoutCherryKeysFlat.stl_43
TRS-80-1978-M1-StandardLayoutCherryKeysFlat.stl_44
TRS-80-1978-M1-StandardLayoutCherryKeysFlat.stl_45
TRS-80-1978-M1-StandardLayoutCherryKeysFlat.stl_46
TRS-80-1978-M1-StandardLayoutCherryKeysFlat.stl_47
TRS-80-1978-M1-StandardLayoutCherryKeysFlat.stl_48
TRS-80-1978-M1-StandardLayoutCherryKeysFlat.stl_49
TRS-80-1978-M1-StandardLayoutCherryKeysFlat.stl_50
TRS-80-1978-M1-StandardLayoutCherryKeysFlat.stl_51
TRS-80-1978-M1-StandardLayoutCherryKeysFlat.stl_52
TRS-80-1978-M1-StandardLayoutCherryKeysFlat.stl_53
Text

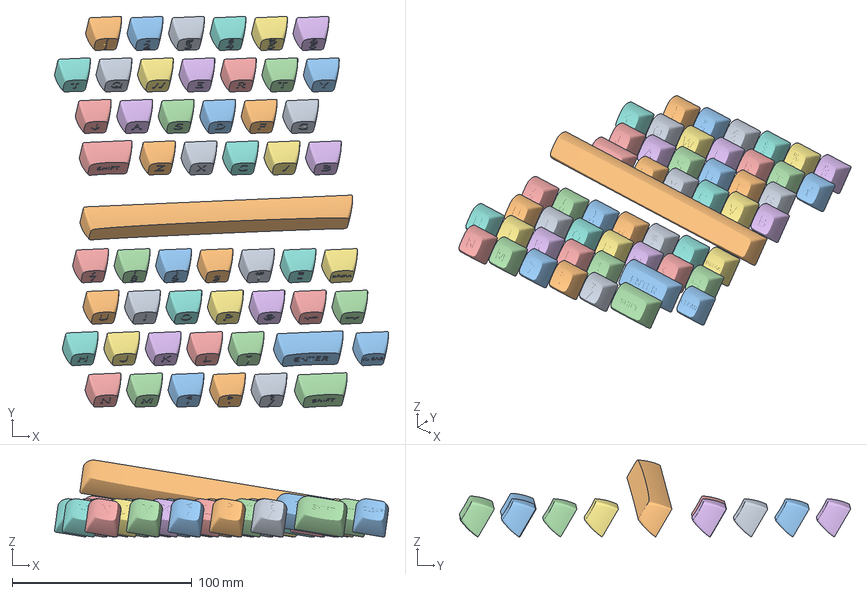
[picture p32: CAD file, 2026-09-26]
openscad/KeyV2-All/TRS-80-1978-M1-StandardLayoutCherryKeysRotatedStems/TRS-80-1978-M1-StandardLayoutCherryKeysRotatedStems-FromSTL.3mf
185.6 x 217.4 x 42.8 mm
TRS-80-1978-M1-StandardLayoutCherryKeysRotatedStems.stl_1
TRS-80-1978-M1-StandardLayoutCherryKeysRotatedStems.stl_2
TRS-80-1978-M1-StandardLayoutCherryKeysRotatedStems.stl_3
TRS-80-1978-M1-StandardLayoutCherryKeysRotatedStems.stl_4
TRS-80-1978-M1-StandardLayoutCherryKeysRotatedStems.stl_5
TRS-80-1978-M1-StandardLayoutCherryKeysRotatedStems.stl_6
TRS-80-1978-M1-StandardLayoutCherryKeysRotatedStems.stl_7
TRS-80-1978-M1-StandardLayoutCherryKeysRotatedStems.stl_8
TRS-80-1978-M1-StandardLayoutCherryKeysRotatedStems.stl_9
TRS-80-1978-M1-StandardLayoutCherryKeysRotatedStems.stl_10
TRS-80-1978-M1-StandardLayoutCherryKeysRotatedStems.stl_11
TRS-80-1978-M1-StandardLayoutCherryKeysRotatedStems.stl_12
TRS-80-1978-M1-StandardLayoutCherryKeysRotatedStems.stl_13
TRS-80-1978-M1-StandardLayoutCherryKeysRotatedStems.stl_14
TRS-80-1978-M1-StandardLayoutCherryKeysRotatedStems.stl_15
TRS-80-1978-M1-StandardLayoutCherryKeysRotatedStems.stl_16
TRS-80-1978-M1-StandardLayoutCherryKeysRotatedStems.stl_17
TRS-80-1978-M1-StandardLayoutCherryKeysRotatedStems.stl_18
TRS-80-1978-M1-StandardLayoutCherryKeysRotatedStems.stl_19
TRS-80-1978-M1-StandardLayoutCherryKeysRotatedStems.stl_20
TRS-80-1978-M1-StandardLayoutCherryKeysRotatedStems.stl_21
TRS-80-1978-M1-StandardLayoutCherryKeysRotatedStems.stl_22
TRS-80-1978-M1-StandardLayoutCherryKeysRotatedStems.stl_23
TRS-80-1978-M1-StandardLayoutCherryKeysRotatedStems.stl_24
TRS-80-1978-M1-StandardLayoutCherryKeysRotatedStems.stl_25
TRS-80-1978-M1-StandardLayoutCherryKeysRotatedStems.stl_26
TRS-80-1978-M1-StandardLayoutCherryKeysRotatedStems.stl_27
TRS-80-1978-M1-StandardLayoutCherryKeysRotatedStems.stl_28
TRS-80-1978-M1-StandardLayoutCherryKeysRotatedStems.stl_29
TRS-80-1978-M1-StandardLayoutCherryKeysRotatedStems.stl_30
TRS-80-1978-M1-StandardLayoutCherryKeysRotatedStems.stl_31
TRS-80-1978-M1-StandardLayoutCherryKeysRotatedStems.stl_32
TRS-80-1978-M1-StandardLayoutCherryKeysRotatedStems.stl_33
TRS-80-1978-M1-StandardLayoutCherryKeysRotatedStems.stl_34
TRS-80-1978-M1-StandardLayoutCherryKeysRotatedStems.stl_35
TRS-80-1978-M1-StandardLayoutCherryKeysRotatedStems.stl_36
TRS-80-1978-M1-StandardLayoutCherryKeysRotatedStems.stl_37
TRS-80-1978-M1-StandardLayoutCherryKeysRotatedStems.stl_38
TRS-80-1978-M1-StandardLayoutCherryKeysRotatedStems.stl_39
TRS-80-1978-M1-StandardLayoutCherryKeysRotatedStems.stl_40
TRS-80-1978-M1-StandardLayoutCherryKeysRotatedStems.stl_41
TRS-80-1978-M1-StandardLayoutCherryKeysRotatedStems.stl_42
TRS-80-1978-M1-StandardLayoutCherryKeysRotatedStems.stl_43
TRS-80-1978-M1-StandardLayoutCherryKeysRotatedStems.stl_44
TRS-80-1978-M1-StandardLayoutCherryKeysRotatedStems.stl_45
TRS-80-1978-M1-StandardLayoutCherryKeysRotatedStems.stl_46
TRS-80-1978-M1-StandardLayoutCherryKeysRotatedStems.stl_47
TRS-80-1978-M1-StandardLayoutCherryKeysRotatedStems.stl_48
TRS-80-1978-M1-StandardLayoutCherryKeysRotatedStems.stl_49
TRS-80-1978-M1-StandardLayoutCherryKeysRotatedStems.stl_50
TRS-80-1978-M1-StandardLayoutCherryKeysRotatedStems.stl_51
TRS-80-1978-M1-StandardLayoutCherryKeysRotatedStems.stl_52
TRS-80-1978-M1-StandardLayoutCherryKeysRotatedStems.stl_53

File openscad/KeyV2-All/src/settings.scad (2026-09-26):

/* [Basic-Settings] */

// Length in units of key. A regular key is 1 unit; spacebar is usually 6.25
$key_length = 1.0; // Range not working in thingiverse customizer atm [1:0.25:16]

// What type of stem you want. Most people want Cherry.
$stem_type = "cherry";  // [cherry, alps, rounded_cherry, box_cherry, filled, disable]

// The stem is the hardest part to print, so this variable controls how much 'slop' there is in the stem
// if your keycaps stick in the switch raise this value
$stem_slop = 0.35; // Not working in thingiverse customizer atm [0:0.01:1]
// broke this out. if your keycaps are falling off lower this value. only works for cherry stems rn
$stem_inner_slop = 0.2;

// Font size used for text
$font_size = 6;

// Set this to true if you're making a spacebar!
$inverted_dish = false;

// change aggressiveness of double sculpting
// this is the radius of the cylinder the keytops are placed on
$double_sculpt_radius = 200;


// Support type. default is "flared" for easy FDM printing; bars are more realistic, and flat could be for artisans
$support_type = "flared"; // [flared, bars, flat, disable]

// Supports for the stem, as it often comes off during printing. Reccommended for most machines
$stem_support_type = "tines"; // [tines, brim, disabled]

// make legends outset instead of inset.
// broken off from artisan support since who wants outset legends?
$outset_legends = false;

/* [Key] */
// Height in units of key. should remain 1 for most uses
$key_height = 1.0;
// Keytop thickness, aka how many millimeters between the inside and outside of the top surface of the key
$keytop_thickness = 1;
// Wall thickness, aka the thickness of the sides of the keycap. note this is the total thickness, aka 3 = 1.5mm walls
$wall_thickness = 3;
// Radius of corners of keycap
$corner_radius = 1;
// Width of the very bottom of the key
$bottom_key_width = 18.16;
// Height (from the front) of the very bottom of the key
$bottom_key_height = 18.16;
// How much less width there is on the top. eg top_key_width = bottom_key_width - width_difference
$width_difference = 6;
// How much less height there is on the top
$height_difference = 4;
// How deep the key is, before adding a dish
$total_depth = 11.5;
// The tilt of the dish in degrees. divided by key height
$top_tilt = -6;
// the y tilt of the dish in degrees. divided by key width.
// for double axis sculpted keycaps and probably not much else
$top_tilt_y = 0;
// How skewed towards the back the top is (0 for center)
$top_skew = 1.7;

// how skewed towards the right the top is. unused, but implemented.
// for double axis sculpted keycaps and probably not much else
$top_skew_x = 0;

/* [Stem] */

// How far the throw distance of the switch is. determines how far the 'cross' in the cherry switch digs into the stem, and how long the keystem needs to be before supports can start. luckily, alps and cherries have a pretty similar throw. can modify to have stouter keycaps for low profile switches, etc
$stem_throw = 4;
// Diameter of the outside of the rounded cherry stem
$rounded_cherry_stem_d = 5.5;


// How much higher the stem is than the bottom of the keycap.
// Inset stem requires support but is more accurate in some profiles
// can be negative to make outset stems
$stem_inset = 0;
// How many degrees to rotate the stems. useful for sideways keycaps
$stem_rotation = 0;
// How many degrees to rotate the keycap, but _not_ inside features (the stem). 
$keycap_rotation = 0;

/* [Shape] */

// Key shape type, determines the shape of the key. default is 'rounded square'
$key_shape_type = "rounded_square";
// ISO enter needs to be linear extruded NOT from the center when not using skin. this tells the program how far up 'not from the center' is
$linear_extrude_height_adjustment = 0;
// How many slices will be made, to approximate curves on corners. Leave at 1 if you are not curving corners
// If you're doing fancy bowed keycap sides, this controls how many slices you take
$height_slices = 1;

/* [Dish] */

// What type of dish the key has. note that unlike stems and supports a dish ALWAYS gets rendered.
$dish_type = "cylindrical"; // [cylindrical, spherical, sideways cylindrical, old spherical, disable]
// How deep the dish 'digs' into the top of the keycap. this is max depth, so you can't find the height from total_depth - dish_depth. besides the top is skewed anyways
$dish_depth = 1;
// How skewed in the x direction the dish is
$dish_skew_x = 0;
// How skewed in the y direction (height) the dish is
$dish_skew_y = 0;


$dish_offset_x = 0;

// If you need the dish to extend further, you can 'overdraw' the rectangle it will hit. this was mostly for iso enter and should be deprecated
$dish_overdraw_width = 0;
// Same as width but for height
$dish_overdraw_height = 0;

/* [Misc] */
// There's a bevel on the cherry stems to aid insertion / guard against first layer squishing making a hard-to-fit stem.
$cherry_bevel = true;

// How tall in mm the stem support is, if there is any. stem support sits around the keystem and helps to secure it while printing.
$stem_support_height = .8;
// Font used for text
$font="DejaVu Sans Mono:style=Book";
// Whether or not to render fake keyswitches to check clearances
$clearance_check = false;
// Should be faster, also required for concave shapes

// what kind of extrusion we use to create the keycap. "hull" is standard, "linear extrude" is legacy, "skin" is new and not well supported.
$hull_shape_type = "hull"; // ["hull", "linear extrude", "skin"]

// This doesn't work very well, but you can try
$rounded_key = false;
//minkowski radius. radius of sphere used in minkowski sum for minkowski_key function. 1.75 for G20
$minkowski_radius = .33;

/* [Features] */

//insert locating bump
$key_bump = false;
//height of the location bump from the top surface of the key
$key_bump_depth = 0.5;
//distance to move the bump from the front edge of the key
$key_bump_edge = 0.4;

/* [Hidden] */

// set this to true if you are making double sculpted keycaps
$double_sculpted = false;

//list of legends to place on a key format: [text, halign, valign, size]
//halign = "left" or "center" or "right"
//valign = "top" or "center" or "bottom"
// Currently does not work with thingiverse customizer, and actually breaks it
$legends = [];

//list of front legends to place on a key format: [text, halign, valign, size]
//halign = "left" or "center" or "right"
//valign = "top" or "center" or "bottom"
// Currently does not work with thingiverse customizer, and actually breaks it
$front_legends = [];

// print legends on the front of the key instead of the top
$front_print_legends = false;

// how recessed inset legends / artisans are from the top of the key
$inset_legend_depth = 0.2;

// Dimensions of alps stem
$alps_stem = [4.45, 2.25];

// Dimensions of choc stem
$choc_stem = [1.2, 3];

// Enable stabilizer stems, to hold onto your cherry or costar stabilizers
$stabilizer_type = "costar_stabilizer"; // [costar_stabilizer, cherry_stabilizer, disable]

// Ternaries are ONLY for customizer. they will NOT work if you're using this in
// OpenSCAD. you should use stabilized(), openSCAD customizer,
// or set $stabilizers directly
// Array of positions of stabilizers
$stabilizers = $key_length >= 6 ? [[-50, 0], [50, 0]] : $key_length >= 2 ? [[-12,0],[12,0]] : [];

// Where the stems are in relation to the center of the keycap, in units. default is one in the center
// Shouldn't work in thingiverse customizer, though it has been...
$stem_positions = [[-5,0]];

// colors
$primary_color = [.2667,.5882,1];
$secondary_color = [.4412, .7, .3784];
$tertiary_color = [1, .6941, .2];
$quaternary_color = [.4078, .3569, .749];
$warning_color = [1,0,0, 0.15];

// how many facets circles will have when used in these features
$minkowski_facets = 30;
$shape_facets =30;



// "flat" / "dished" / "disable"
$inner_shape_type = "flat";

// default side_sculpting function, linear
$side_sculpting = function(progress) 0;
$corner_sculpting = function(progress) 0;

// you probably shouldn't touch this, it's internal to sculpted_square
// modify side sculpting with the $side_sculpting function in the key profile files
$more_side_sculpting_factor = 0;

// 3d surface functions (still in beta)
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

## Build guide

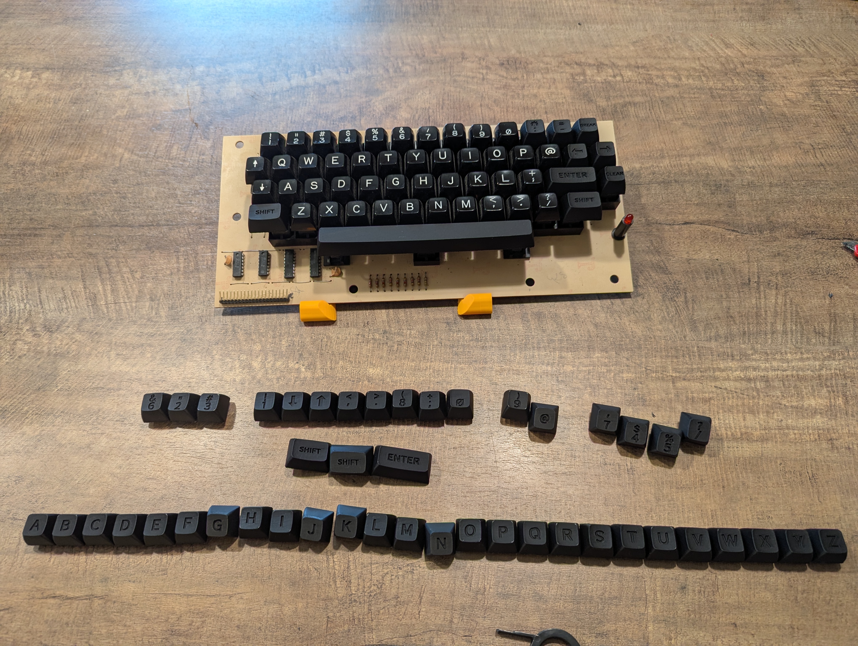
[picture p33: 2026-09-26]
images/m1keys-installing.jpg

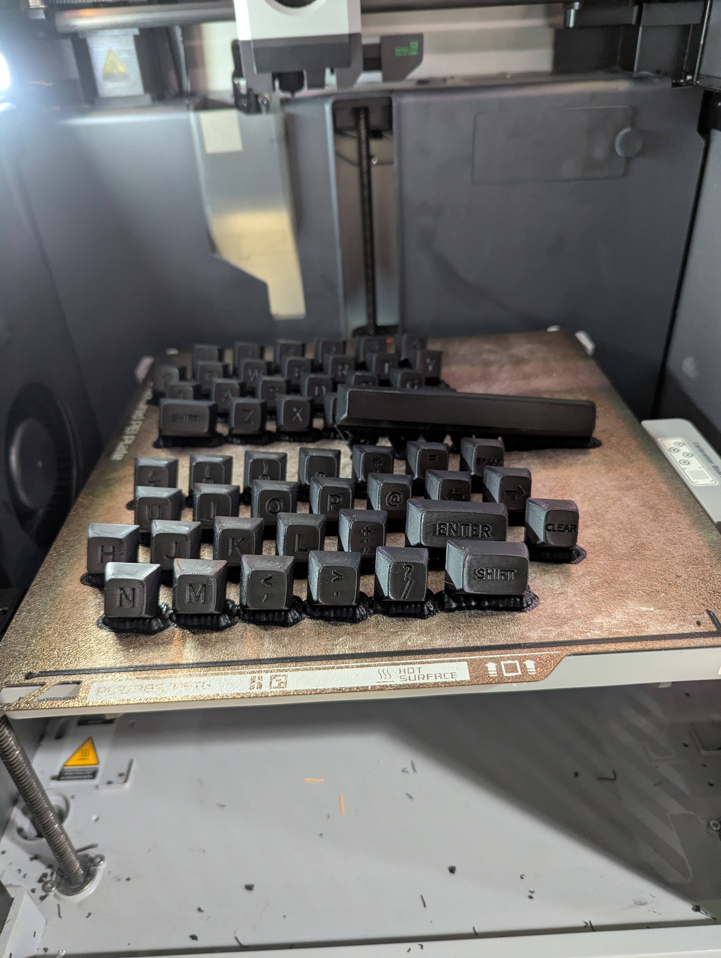
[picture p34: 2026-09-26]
images/InPrinter.jpg
